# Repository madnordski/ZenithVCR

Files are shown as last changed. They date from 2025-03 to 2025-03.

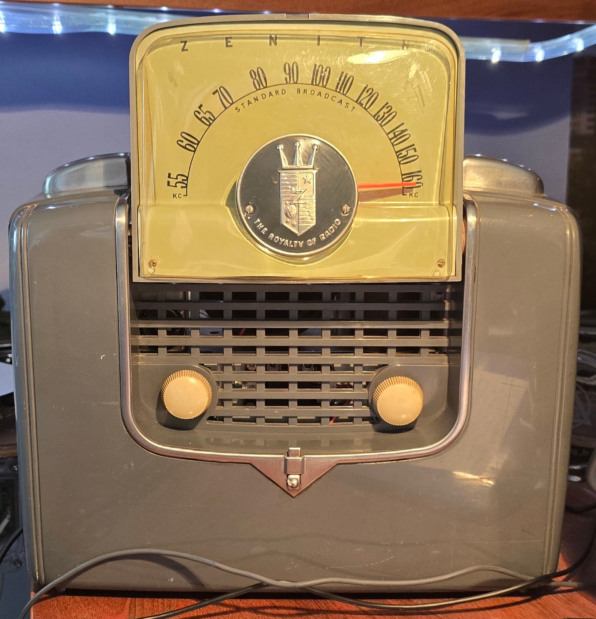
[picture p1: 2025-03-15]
Parts/Zenith4G90t2.jpg

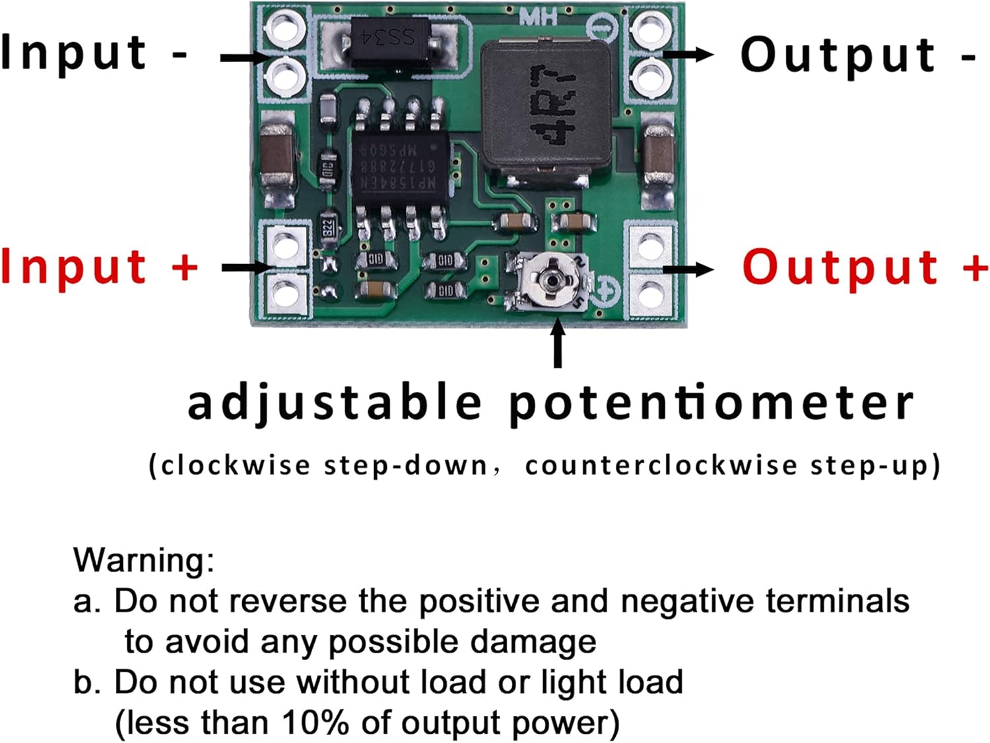
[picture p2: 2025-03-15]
Parts/adjustable_buck_converter1.jpg

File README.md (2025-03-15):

# ZenithVCR
This repository is for the **Zenith Voice Controlled Radio**.
- by J.King, March 2025
- Special thanks to OpenAI’s ChatGPT for assistance with debugging, Flask optimization, and streaming improvements.
## 🎵 Overview
This project brings a **1940s Zenith Radio** back to life with modern streaming capabilities! It features:
- **ESP32-S3 N8R2 DevKitC** as the core controller (w/at least 2MB PSRAM).
- **Python Flask Server** for serving music, managing playlists and serving podcasts.
- **Voice control** via the **DFRobot SEN0539-EN** module.
- **Stepper-motor-controlled tuning dial** for station selection.
- **Wi-Fi connectivity** with adaptive access point switching.

## 🛠️ Features
✅ **Stream Internet Radio, Podcasts, and Local MP3/OGG Files**  
✅ **Control Playback via Voice Commands or Encoder Knob w/Button**  
✅ **mDNS for Easy Web Interface Access**  
✅ **Multi-Threaded Flask Server for Smooth UI & Streaming**  
✅ **Auto-Switching Between Wi-Fi Access Points**  
✅ **Creates Access Point for Easy WiFi Setup**  
✅ **Web Interface for entering Internet Radio Station URLs**

## 🔧 Hardware Used
- **ESP32-S3 DevKitC-1 (YD-ESP32-S3 N8R2)**
- **DFRobot SEN0539-EN Speech Recognition Module**
- **Stepper Motor (PM08-2) & Controller (TMC2209) for Dial Pointer**
- **Permanent Magnet Speaker (Replaced Original Field Coil)**
- **9V 3A Power Supply + Buck/Boost Converters**
- **Vintage 1940s Zenith 4G903 Radio Chassis**

## 🖥️ How It Works
### **1️⃣ Python Flask Server (Raspberry Pi / Linux)**
- Hosts music via **FFmpeg for real-time transcoding**.
- Serves a **web-based album browser at http://zenithvcr:8001/** for easy selection.
- Runs two Flask servers:
  - **Port 8000:** Streaming server (used by ESP32 to play local content).
  - **Port 8001:** Web UI for album selection.
- **mDNS** so any computer on your network can find the Flask servers**
  - **http://zenithvcr:8001/browse**

### **2️⃣ ESP32-S3 (Zenith Voice Controlled Radio)**
- Fetches music from the server.
- Uses **I²C speech recognition** for voice control.
- Switches between **Internet radio, local MP3s, and podcasts**.
- The station playing is indicated by an **interactive tuning dial**.
- **Serves a webpage at zenith.local** for changing Internet Radio URLs.
  - this page also includes a complete list of the voice commands.
- Press and hold the volume knob when turning on to setup WiFi for your network.
  - Connect to access point, **Zenith Setup** and IP **192.168.1.4**.

## 🚀 Installation & Setup
### **1** Optionally, Set Up the Flask Music Server
The Zenith Voice Controlled Radio does not depend on the Flask Server.
It's used only to serve your local content to the Zenith.
#### **Install Dependencies**
```sh
pip install flask gevent ffmpeg-python
python3 stream_machine.py
```
### **2** Flash the ESP32 with the Radio Firmware
Use Arduino IDE or PlatformIO to upload the code.
🎙️ Voice Commands
(these are configured by you.  Follow the DFRobot SEN0539 instructions).
The code burned into the ESP32 is ready to respond to commands
like the following.  Use http://zenith.local to associate your voice
commands to all the tasks defined in the code.
### Command	Action (complete list at zenith.local)
#### "Hello robot, pause radio"	  stops playback
#### "Hello robot, resume radio"	resumes where it left off
#### "Hello robot, volume up"     turns up the volume
#### "Hello robot, volume down"   turns down the volume
#### "Hello robot, station up"    moves the dial up one station
#### "Hello robot, station down"  moves the dial down one station

### **3** Put the Zenith Voice Controlled Radio on your Network
When the Zenith runs for the first time, it creates an access point called "Zenith Setup".
You can always force the Zenith into access point mode by holding in the volume knob when
powering on.
#### Step a. Connect your phone or computer WiFi to Zenith Setup.
#### Step b. Go to http://192.168.1.4 to enter the WiFi Credentials
#### Step c. Update and restart the Zenith (follow instructions)
#### Step d. Now you can define your Internet radio stations using http://zenith.local.
#### Step e. Enjoy!
#### Step f. If you are running the Flask server, enter the streaming url (use IP) at http://zenith.local.

🎛️ Web Interface for locally served content (Flask Server)
### Access the album browser at http://zenithvcr.local:8001
### Stream control handled at http://zenithvcr.local:8000/stream
⚡ Troubleshooting
### Problem: Web interface is slow while streaming
✅ Solution: Flask now runs two separate servers (8000 & 8001) to keep the UI responsive.

### Problem: ESP32 disconnects and Flask hangs
✅ Solution: Improved error handling ensures FFmpeg stops properly.

### Problem: Album names with special characters break requests
✅ Solution: URLs are properly encoded & decoded in JavaScript and Flask.

📜 License
### GPL-3.0 - Open Source! Feel free to modify and improve provided you pass on your work to others.

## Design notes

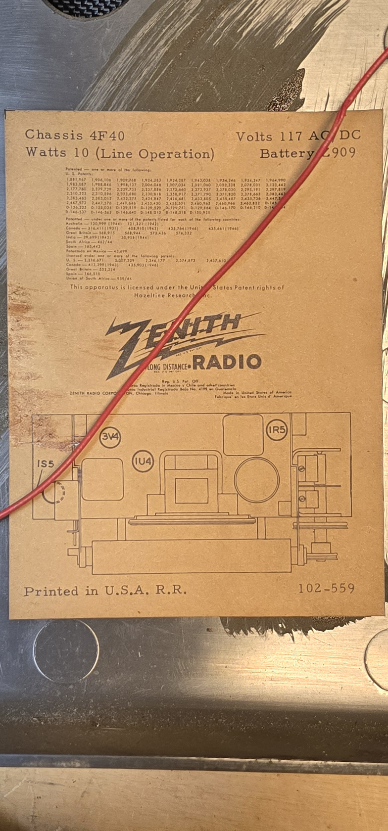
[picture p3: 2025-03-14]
photos/20250121_075358_resized.jpg

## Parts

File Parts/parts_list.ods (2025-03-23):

Zenith Voice Controlled Radio Parts List
Part | Link (non-sponsored)
ESP32-S3 DevKitC-1 N8R2 | https://www.amazon.com/dp/B0DFTKFWT2?ref_=ppx_hzsearch_conn_dt_b_fed_asin_title_1
DFRobot SEN0539 | https://www.dfrobot.com/product-2665.html
Stepper Motor | https://www.amazon.com/dp/B08346RFVZ?ref_=ppx_hzsearch_conn_dt_b_fed_asin_title_3
TMC2209 | https://www.amazon.com/HiLetgo-Printer-TMC2209-Stepper-Replace/dp/B0832SK397
MAX98357 | https://www.amazon.com/dp/B0912CWB7Z?ref_=ppx_hzsearch_conn_dt_b_fed_asin_title_1&th=1
Rotary Encoders (2) | https://www.amazon.com/dp/B09KNC1J6H?ref_=ppx_hzsearch_conn_dt_b_fed_asin_title_1
Reed switch | https://www.amazon.com/dp/B07WQVLRQC?ref_=ppx_hzsearch_conn_dt_b_fed_asin_title_1
Speaker (for radio) | https://www.amazon.com/dp/B001RNNX8U?ref_=ppx_hzsearch_conn_dt_b_fed_asin_title_1&th=1
Speaker (for DFRobot) | https://www.amazon.com/dp/B0C49TKSQQ?ref_=ppx_hzsearch_conn_dt_b_fed_asin_title_3&th=1
Adjustable Buck Converter (before wiring, adjust to 5.1 volts) | https://www.amazon.com/dp/B07RVG34WR?ref_=ppx_hzsearch_conn_dt_b_fed_asin_title_1&th=1
USB Buck Converter | https://www.amazon.com/dp/B01HXU1C6U?ref_=ppx_hzsearch_conn_dt_b_fed_asin_title_1
9V Power Supply | https://www.amazon.com/dp/B08L99PTDH?ref_=ppx_hzsearch_conn_dt_b_fed_asin_title_1&th=1
Red LED
Green LED
220 ohm resisters (2)
1K ohm resistor
100K ohm resistor

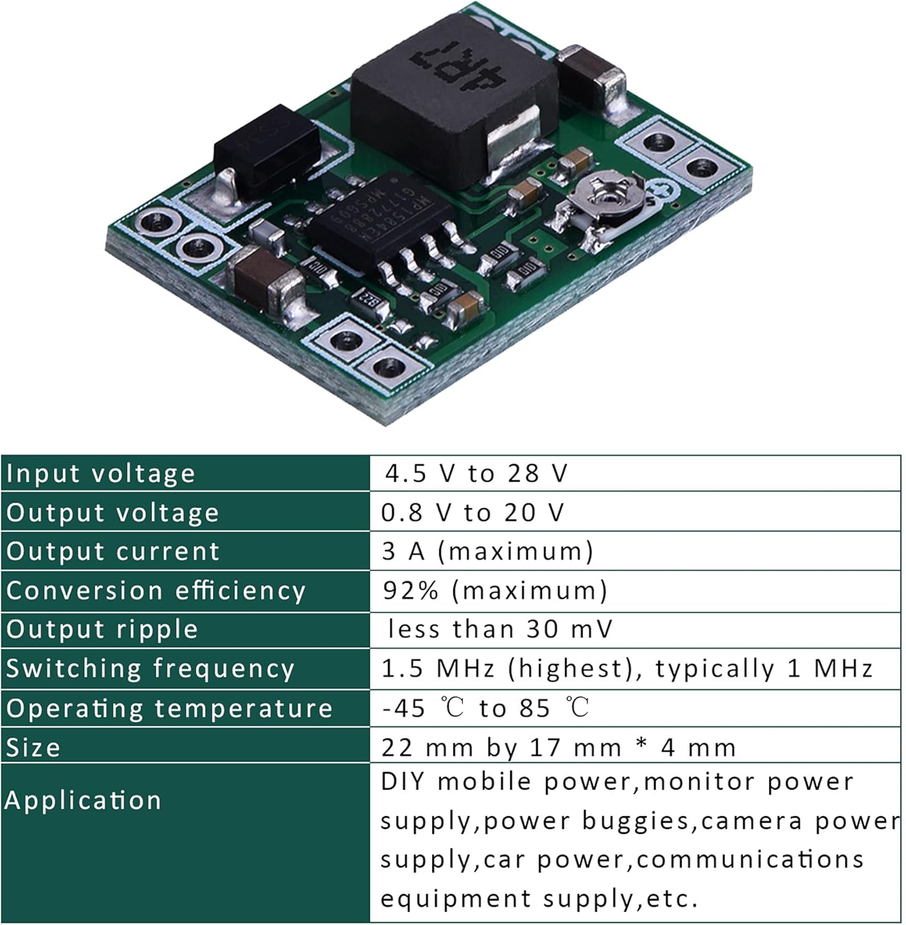
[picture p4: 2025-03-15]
Parts/adjustable_buck_converter2.jpg

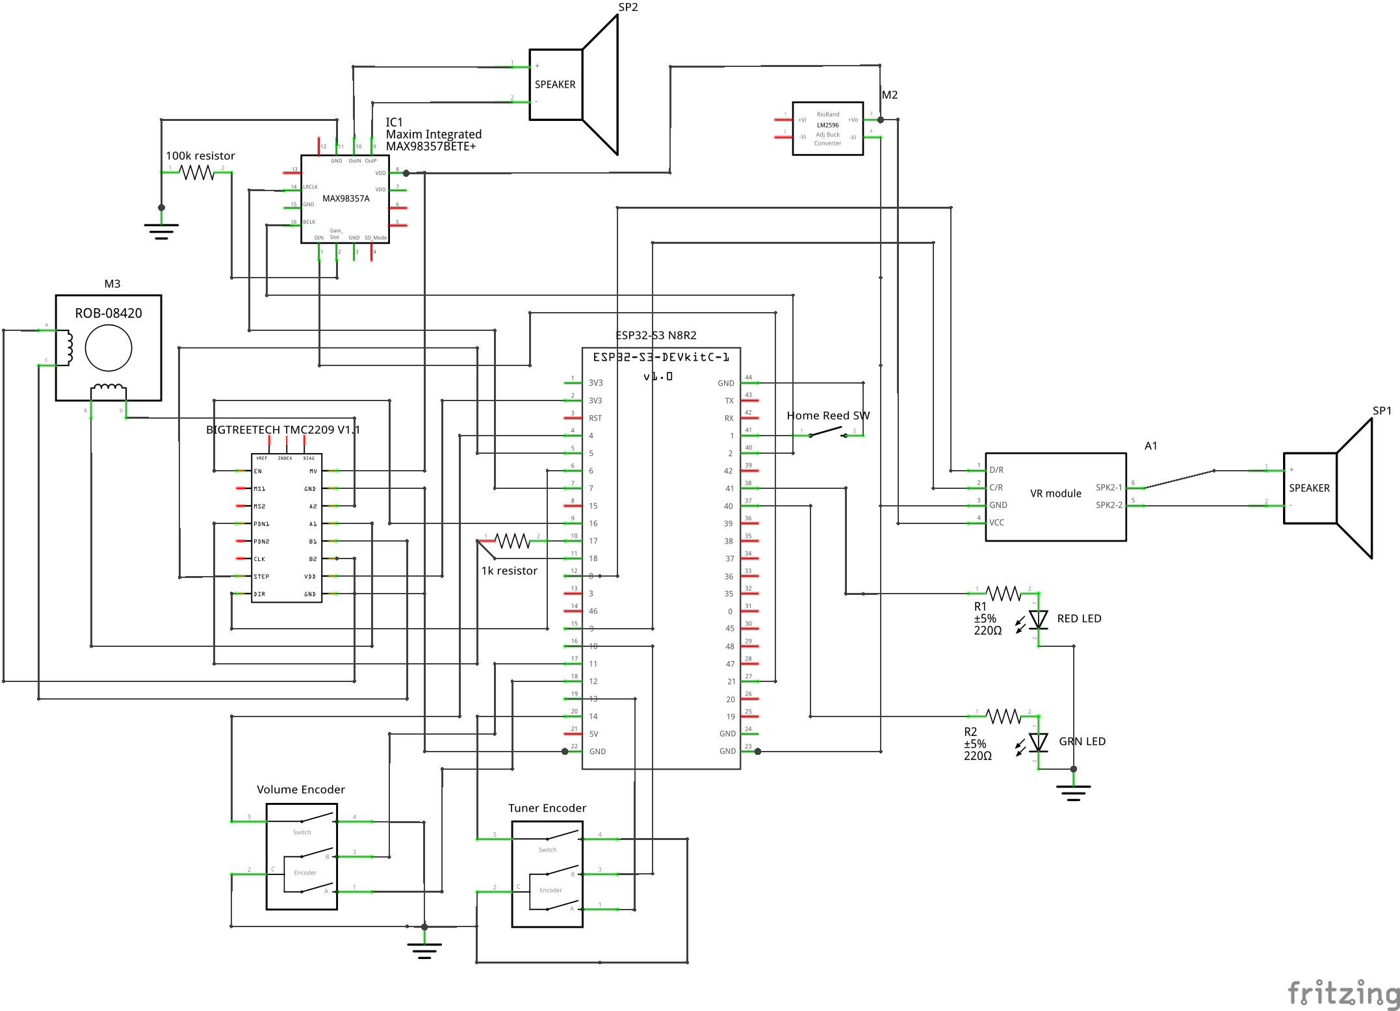
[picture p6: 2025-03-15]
Parts/zenith_schem.png

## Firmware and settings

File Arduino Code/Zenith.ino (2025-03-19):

/** Zenith

  The Zenith Voice Controlled Internet Radio. The idea is we will
  replace the innards of a vintage radio with an ESP32-S3 that plays
  Internet radio and is controlled by voice commands.

  Voice control is handled by the DFRobot SEN0539 Language Recognition
  Sensor. This sensor is able to learn one wake-word and 17 voice
  commands. It conects to our ESP32-S3 over I2C.

  IMPORTANT: The Zenith serves a webpage for configuring the WiFi and
  Internet Radio URLs.  When it is unable to connect to WiFi or WHEN
  THE VOLUME KNOB IS PRESSED IN AT STARTUP, Zenith creates an access
  point called "Zenith Setup" and serves the webpage at 192.168.1.4.
  You can always access this webpage when Zenith is on your home WiFi
  by going to http://zenith.local.
  
  The ESP32 has a stepper motor under its control that moves the dial
  pointer. The stepper driver is the TMC2209 and is controlled to the
  ESP32 by a few GPIO pins and configured using a hardward serial
  UART.  There is a small magnet on the pointer that is sensed by a
  reed switch mounted under the dial face. This is used to home the
  pointer at startup.

  Being an Internet radio, the ESP32-S3 sends audio over I2S (not a
  typo), to a MAX98357 audio amplifier.

  Finally, the operations of the volume and tuner knobs are handled by
  two rotary encoders. The volume knob controls volume and pressing it
  in toggles the mute state.  The Tuner know controls which Internet
  radio station is playing. Pressing the turn knob in only matters
  with the radio is tuned to a local stream (special channel). When
  this is the case, pressing the tuner in will play the next track in
  the stream.
  
  @author J. King
  @date 5 February 2025
  @copy All rights reserved.
  @brief discription
  
  $Revision: 1.57 $
  $Date: 2025/03/19 21:15:12 $

*/

// Include required libraries
#include <Arduino.h>
#include <esp_system.h>
#include <Preferences.h>

#include <WiFi.h>
#include <ESPmDNS.h>
#include "Audio.h"
#include <HardwareSerial.h>
#include <TMCStepper.h>
#include "DFRobot_DF2301Q.h"
#include "GetRequestParser.h"
#include "index.h"
#include "index2.h"
#include "index3.h"

// debug
//#define DEBUG

#ifdef DEBUG
#define sp1(x)   Serial.println(x)
#define sp2(x,y) Serial.print(x);Serial.println(y)
#define sp2s(x,y) Serial.print(x);Serial.print(" ");Serial.println(y)
#else
#define sp1(x)
#define sp2(x,y)
#define sp2s(x,y)
#endif

// simplify serial print when debugging isn't desired
#define sp2sx(x,y) Serial.print(x);Serial.print(" ");Serial.println(y)
#define sp2x(x,y) Serial.print(x);Serial.println(y)
#define sp1x(x)   Serial.println(x)

// CONNECTION FOR YD ESP32-S3 DEVKITC-1 N8R2 (2 MB PSRAM, 8 MB FLASH)
// GPIO

const gpio_num_t mutePin = GPIO_NUM_4;      // the volume encoder push button
const gpio_num_t nextTrackPin = GPIO_NUM_14; // the favorite station push button

// Define I2S connections for audio output
#define I2S_DOUT  GPIO_NUM_21
#define I2S_BCLK  GPIO_NUM_2   // sck
#define I2S_LRC   GPIO_NUM_7  // ws

// STATION LIST
#define STATION_LIMIT       13  // 13 STATION LIMIT, one for each dial number
#define STATION_CHAR_LIMIT 256  // character length limit for station entries

// the station list set of keys
char *staIds[] = {"sta55", "sta60", "sta65", "sta70", "sta80", "sta90",
		  "sta100", "sta110", "sta120", "sta130", "sta140",
		  "sta150", "sta160"};

// the task ids, set of keys
const int nTaskIds = 17;
char *tskIds[] = {"tsk10", "tsk11", "tsk12", "tsk13", "tsk14", "tsk15",
		  "tsk16", "tsk17", "tsk18", "tsk19", "tsk20",
		  "tsk21", "tsk22", "tsk23", "tsk24", "tsk25", "tsk26"};

// normal loop or settings loop
bool gAPMode = false;

// we will populate this list from preferences and have web page for
// configuring new or additional stations up STATION_LIMIT (limited to
// 13), one for each dial number.

char *gStationList[STATION_LIMIT] = {0};
int gNumberOfStations = 0;
const int localStreamPos = 11;
const int localPodcastPos = 12;
bool gSkipRequest = false;

// COMMAND LIST -- populated from violet unless fails then prefs
// This list maps voice commands to tasks.

#define COMMAND_LIMIT      256
int8_t gCommands[COMMAND_LIMIT];  // sparsely populated lookup table
int gNumCommands = 0;

// Save the last station used, the volume level, wifi settings and the
// list of stations to preferences.

Preferences prefs;

// I2C for communicating with the DFRobot SENS0539-EN voice
// recognition module

DFRobot_DF2301Q_I2C zenith;

// Create audio object
Audio audio;

// Wifi Credentials, taken from prefs
char ssids[2][32];  
char password[2][80];
int gCurrentSSID = 0;
const int rssiMinimum = -65; // switch access points when signal gets
			     // marginal

// WiFi Access Point for setting passwords and station urls
const char *apSSID = "Zenith Setup";

// we also run an http server for configuring the Zenith VC Radio
NetworkServer server(80);

// LEDs
const gpio_num_t grnLed = GPIO_NUM_40;
const gpio_num_t redLed = GPIO_NUM_41;

// reed switch for homing
const int homePin = GPIO_NUM_1;

// stepper motor definition
#define EN_PIN    GPIO_NUM_16   // Enable pin (wired to ground)
#define DIR_PIN   GPIO_NUM_6   // Direction pin
#define STEP_PIN  GPIO_NUM_5   // Step pin
#define UART_RX   GPIO_NUM_18   // UART RX (TMC2209 TX)
#define UART_TX   GPIO_NUM_17   // UART TX (TMC2209 RX)

#define R_SENSE 0.11f    // Sense resistor value
#define DRIVER_ADDRESS 0 // Default address for TMC2209

#define DIRECTION_CW  LOW
#define DIRECTION_CCW   HIGH
#define SPEED_FAST   10  // might be too fast for most tasks
#define SPEED_MEDIUM 5
#define SPEED_SLOW   0

#define STEPPER_CURRENT 80 // around 56 mA is as low as it will go
#define STEPPER_SPEED   SPEED_SLOW
#define MICRO_STEPS     16

// This are emperically determined stepper positions for each dial
// number.
// Zero is when the needle is against the left stop.
const int numPos = 14;
const int dialPosition[] = {0, 9, 25, 39, 50, 67, 80, 92, 105,
			  //  55  60  65  70  80  90 100  110
			    116, 126, 137, 146, 157};
                         // 120  130  140  150  160

int gCurrentIndex = 0;

// this configures the stepper motor driver with a serial connect
TMC2209Stepper driver(&Serial1, R_SENSE, DRIVER_ADDRESS);

// Tuner and Volume encoder definitions
#define TUNER_APIN GPIO_NUM_13
#define TUNER_BPIN GPIO_NUM_10
#define VOLUME_APIN GPIO_NUM_12
#define VOLUME_BPIN GPIO_NUM_11
#define MAX_VOLUME 100

// timing constants
const unsigned long encDebounceMS = 10;
const unsigned long encWindow = 500; // consistent results or forget

// encoder knob position
volatile int gTunEncoderPos = 0;
volatile int gVolEncoderPos = 22;
volatile unsigned long gPlayStart = 0;
volatile unsigned long gPlayTime = 0;

///////////////  INTERRUPTS ///////////////////////////////////////

/** tunerEncoderISR
    This interrupt updates the value stored in gTunEncoderPos.
    This is triggered on an A pulse, the state of B tells us the
    direction. Because encoders are mechanical switches, we need to
    debounce them.
*/

// Tuner (T) ISR function for reading A pulses
unsigned long encTLastPulse = 0;
int lastTResult = 0; // require pause before changing direction

static void IRAM_ATTR tunerEncoderISR(void *arg) {
  int8_t bStateSum = 0;
  int8_t result;
  int rtn = gTunEncoderPos;
  
  for (int i=0; i<4; i++) {
    bStateSum += digitalRead(TUNER_BPIN) == HIGH ? 1 : 0; // try to debounce B
    delayMicroseconds(100);
  }

  // only concensus readings are accepted
  if ( bStateSum == 0 || bStateSum == 4 ) {
    result = bStateSum < 2 ? 1 : -1;

    // debounce and delay turning around to get smooth forward or
    // reverse changes
    if ( millis() - encTLastPulse > encDebounceMS ) { // debounce A
      if ( result == lastTResult || millis() - encTLastPulse > encWindow ) {
	rtn = gTunEncoderPos + result;
	lastTResult = result;
	encTLastPulse = millis();
      }
    }
  }
  // clip to our station list
  if ( rtn >= gNumberOfStations )
    gTunEncoderPos = gNumberOfStations - 1;
  else if ( rtn < 0 )
    gTunEncoderPos = 0;
  else
    gTunEncoderPos = rtn;
}

/** volumeEncoderISR
    This interrupt updates the value stored in gVolEncoderPos.
    This is triggered on an A pulse, the state of B tells us the
    direction. Because encoders are mechanical switches, we need to
    debounce them.
 */

// Volume (V) ISR function for reading A pulses
unsigned long encVLastPulse = 0;
int lastVResult = 0; // require pause before changing direction

static void IRAM_ATTR volumeEncoderISR(void *arg) {
  int8_t bStateSum = 0;
  int8_t result;
  int rtn = gVolEncoderPos;
  
  for (int i=0; i<4; i++) {
    bStateSum += digitalRead(VOLUME_BPIN) == HIGH ? 1 : 0; // try to debounce B
    delayMicroseconds(100);
  }

  // accept consensus values only
  if ( bStateSum == 0 || bStateSum == 4 ) {
    result = bStateSum < 2 ? 1 : -1;

    // smooth transiition
    if ( millis() - encVLastPulse > encDebounceMS ) { // debounce A
      if ( result == lastVResult || millis() - encVLastPulse > encWindow ) {
	rtn = gVolEncoderPos + result;
	lastVResult = result;
	encVLastPulse = millis();
      }
    }
  }
  // clip volume
  if ( rtn >= MAX_VOLUME )
    gVolEncoderPos = MAX_VOLUME;
  else if ( rtn < 0 )
    gVolEncoderPos = 0;
  else
    gVolEncoderPos = rtn;
}

/** muteEncoderISR

    This ISR sets the state of gPlay.
    Interrupt routine to handle the button press of the volume
    encoder. It toggles the pause/resume state of Internet Radio.
*/

volatile bool gPlay = true;

unsigned long btnDebounceMS = 500;
unsigned long muteLastPress = 0;
unsigned long muteBtnDebounce = btnDebounceMS * 2;

static void IRAM_ATTR muteEncoderISR(void *arg) {
  if ( millis() - muteLastPress > muteBtnDebounce ) { // debounce
    if ( gPlay )
      gPlay = false;
    else
      gPlay = true;
    muteLastPress = millis();
  }
}

/** nextTrackEncoderISR

    This ISR sets the state of gNextTrack which advances the playback
    of local music one track.
    Interrupt routine to handle the button press of the tuner
    encoder. This button is only active when the station is set to
    STREAM LOCAL.
*/

volatile bool gNextTrack = false;
unsigned long nextTrackPress = 0;

static void IRAM_ATTR nextTrackEncoderISR(void *arg) {
  if ( millis() - nextTrackPress > btnDebounceMS ) { // debounce
    gNextTrack = true;
    nextTrackPress = millis();
  }
}

/** playStationTask

    This task just keeps the radio playing.  The station is selected
    elsewhere.  It is paused by setting gPlay to false.
*/

TaskHandle_t PlayStationHandle;
int gPlayParam = 0;

void playStationTask(void *pvParams) {
  bool state = gPlay;

  while ( true ) {
    if ( gPlay ) {
      audio.loop();
    }
      
    vTaskDelay(1/portTICK_PERIOD_MS);
  }
}

/** zenithVCTask

    This task handles the voice commands.  When you say, "Hello,
    Robot" and the DFRobot SEN0539 recognizes this the wake-word, the
    radio will be paused.  It is then ready to recieve a command.
    BTW: by pressing the volume knob to pause the radio before saying
    "Hello, robot", is adviced.

    There are primary control commands and commands for specific
    Internet Radio Stations.  You can reprogram the DFRobot without
    writing code but the code here would need to change to add and
    delete tasks.  If you reprogram the DFRobot Voice Commands, these
    can be mapped to the tasks coded using a text file served by a
    local webserver.  Changing the webserver IP, however, requires
    modification of this program.
    
    FYI: the purpose of pause/resume radio is to allow programming of
    the DFRobot or for verifying the voice command ids.

*/
    
TaskHandle_t ZenithVCHandle;
int gTaskVar = 0;
bool gRadioOff = false; // use this to train the sen0539 language
			// recognition sensor
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
void loop() {
  if ( !gAPMode ) mainLoop();
  setupLoop();  
}

GetRequestParser reqParser;

void setupLoop() {
  WiFiClient client = server.accept();

  // stannn=url is 7 characters, 4*32 for password settings
  // nb: special characters can extend data beyond the prediction
  // (e.g. & becomes %26) but user input is restricted by characters typed
  //const size_t maxDataSize = 4*32 + STATION_LIMIT*STATION_CHAR_LIMIT;
  const size_t maxLineSize = STATION_LIMIT*7 + STATION_LIMIT*STATION_CHAR_LIMIT;
  const size_t maxValueSize = STATION_CHAR_LIMIT;
  
  if ( client ) {
    char line[maxLineSize];
    int idx = 0;
    bool espRestart = false;
    bool havePost = false;
    bool cmdTskChange = false;
    
    sp1("client connected");
    
    while ( client.connected() ) {
      if ( client.available() ) {
	char c = client.read();
	Serial.write(c);
	
	if ( c == '\n' ) {
	  if ( strstr(line, "POST ") ) {
	    havePost = true;
	  }
	  if ( strstr(line, "GET") ) {
	    char name[maxValueSize], value[maxValueSize];
	    int err;
	    
	    sp2("LINE: ", line);
	    sp2("Line size: ", strlen(line));
	    
	    if ( (err = reqParser.parse(line, false)) == REQPARSE_OKAY ) {
	      sp1("PARSED---------");
	      while ( reqParser.nextRequest(name, value, maxValueSize) ) {
		sp2sx(name, value);
		if ( strcmp(name, "Restart") == 0 ) espRestart = true;
	      }
	      if ( espRestart ) {
		// back to normal operation
		client.clear();
		client.stop();
		ESP.restart();
	      }
	    }
	  }
	  
	  if ( idx == 0 ) {
	    if ( havePost ) {
	      // POST content here
	      sp1("********* POST EVENTS HERE ********");
	      char *p = line;
	      *p = '\0';
	      while ( client.available() ) {
		char c = client.read();
		Serial.write(c);
		*p = c;
		p++;
		*p = '\0';
	      }
	      sp2("L:", line);
	      char name[maxValueSize], value[maxValueSize];
	      int err;
	      cmdTskChange = false;
	      
	      sp2("LINE: ", line);
	      sp2("Line size: ", strlen(line));
	      
	      if ( (err = reqParser.parse(line, true)) == REQPARSE_OKAY ) {
		while ( reqParser.nextRequest(name, value, maxValueSize) ) {
		  sp2sx(name, value);
		  if ( strstr(name, "tsk") == NULL ) {
		    prefs.putString(name, value); // update the string settings
		  }
		  if ( strcmp(name, "ssid1") == 0 ) strcpy(ssids[0], value);
		  if ( strcmp(name, "ssid2") == 0 ) strcpy(ssids[1], value);
		  if ( strcmp(name, "pw1") == 0 ) strcpy(password[0], value);
		  if ( strcmp(name, "pw2") == 0 ) strcpy(password[1], value);
		  for (int i=0; i<STATION_LIMIT; i++) {
		    if ( strcmp(name, staIds[i]) == 0 ) {
		      strcpy(gStationList[i], value);
		    }
		  }
		  // update integer settings
		  for (int i=0; i<nTaskIds; i++) {
		    if ( strcmp(name, tskIds[i]) == 0 ) {
		      int cId = atoi(value);
		      int tId = atoi(name+3);
		      sp2sx(cId, tId);
		      if ( cId >= 0 && cId < COMMAND_LIMIT ) {
			// update prefs, before we can update the
			// gCommands table, we need to clear it out
			// (see below)
			prefs.putInt(name, cId);
			cmdTskChange = true;
		      }
		    }
		  }
		}
	      }
	      else {
		if ( err == REQPARSE_NO_QUERY_ERR ) {
		  sp2("No query error ", err);
		}
		else if ( err == REQPARSE_MALLOC_ERR ) {
		  sp2("Memory allocation error ", err);
		}
		else {
		  sp2("Unspecified error ", err);
		}
	      }
	      Serial.println("********* END POST EVENTS *************");
	    }

	    // IF CMD/TSK CHANGE: NEED TO CLOSE AND REOPEN PREFERENCES
	    //  this clears the cache and prevents busy errors
	    // use prefs, it gives us a lookup by task id
	    // start a reply
	    if ( cmdTskChange ) {
	      prefs.end();
	      prefs.begin("Zenith");
	      // reestablish the sparse command to task array
	      for (int i=0; i<COMMAND_LIMIT; i++) {
		// must clear out changed values
		gCommands[i] = 0;
	      }
	      for (int i=0; i<nTaskIds; i++) {
		// populate with the currently saved settings
		int cId = prefs.getInt(tskIds[i]);
		int tId = atoi(tskIds[i]+3);
		gCommands[cId] = tId;
	      }
	    }

	    // response starts here
	    client.println("HTTP/1.1 200 OK");
	    client.println("Content-type:text/html");
	    client.println();

	    // html text of the page
	    client.print(index_html);
	    
	    // Let's try to calculate the predicted data size to determine
	    // allocated size for the first set to data values
	    sp2("size of index2 = ", sizeof(index2_html));
	    size_t predictedSize = sizeof(index2_html) + 4 * 80;
	    for (int i=0; i<STATION_LIMIT; i++) {
	      predictedSize += (strlen(gStationList[i])+1);
	    }
	    
	    // send back the settings for wifi and urls
	    char *buf1 = (char *)malloc(predictedSize);
	    if ( buf1 == NULL ) {
	      sp1x("Failed to allocate memory!!!");
	      vTaskDelay(100000/portTICK_PERIOD_MS);
	    }

	    snprintf(buf1, predictedSize, index2_html,
		    ssids[0], password[0], ssids[1], password[1], //  4
		    gStationList[0], gStationList[1],
		    gStationList[2], gStationList[3],
		    gStationList[4], gStationList[5],            // 10
		    gStationList[6], gStationList[7],
		    gStationList[8], gStationList[9],
		    gStationList[10], gStationList[11],           // 16
		    gStationList[12]
		    );

	    // did we exceed the length!?! (should be impossible)
	    sp2("allocated buf1: ", predictedSize);
	    sp2("buf1 size: ", strlen(buf1));
	    if ( strlen(buf1) >= predictedSize ) {
	      sp1x("\n************ WEB PAGE MEMORY EXCEEDED **************");
	      sp1x("restarting...");
	      ESP.restart();
	    }
	    sp1("Sending to client...");
	    sp2("Heap ", ESP.getFreeHeap());
	    client.print(buf1);
	    free(buf1);

	    // Let's try to calculate the predicted data size to determine
	    // allocated size for the second set to data values
	    sp2("size of index3 = ", sizeof(index3_html));
	    predictedSize = sizeof(index3_html) + 8 * nTaskIds;
	    
	    // send back the settings for wifi and urls
	    buf1 = (char *)malloc(predictedSize);
	    if ( buf1 == NULL ) {
	      sp1x("Failed to allocate memory!!!");
	      vTaskDelay(100000/portTICK_PERIOD_MS);
	    }

	    snprintf(buf1, predictedSize, index3_html,
		     prefs.getInt("tsk10"), prefs.getInt("tsk11"),
		     prefs.getInt("tsk12"), prefs.getInt("tsk13"),
		     prefs.getInt("tsk14"), prefs.getInt("tsk15"),
		     prefs.getInt("tsk16"), prefs.getInt("tsk17"),
		     prefs.getInt("tsk18"), prefs.getInt("tsk19"),
		     prefs.getInt("tsk20"), prefs.getInt("tsk21"),
		     prefs.getInt("tsk22"), prefs.getInt("tsk23"),
		     prefs.getInt("tsk24"), prefs.getInt("tsk25"),
		     prefs.getInt("tsk26")
		    );

	    // did we exceed the length!?! (should be impossible)
	    sp2x("allocated buf1: ", predictedSize);
	    sp2x("buf1 size: ", strlen(buf1));
	    if ( strlen(buf1) >= predictedSize ) {
	      sp1x("\n************ WEB PAGE MEMORY EXCEEDED **************");
	      sp1x("restarting...");
	      ESP.restart();
	    }
	    sp1x("Sending final part to client...");
	    sp2x("Heap ", ESP.getFreeHeap());
	    client.print(buf1);
	    vTaskDelay(500/portTICK_PERIOD_MS);
	    free(buf1);

	    // end of response
	    client.println();
	    break;
	  }
	  else {
	    idx = 0;
	    line[idx] = '\0';
	  }
	}
	else if ( c != '\r' ) {
	  line[idx] = c;
	  idx++;
	  line[idx] = '\0';
	  if ( idx > maxLineSize ) {
	    sp2("Line size exceeded!!! Size=", idx);
	  }
	}
      }
    } // end while client connected

    // clear the channel and stop the client
    idx = 0;
    client.clear();
    client.stop();
    sp1("Client disconnected.\n");
  } // end if client
} // end setupLoop
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

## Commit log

2025-03-14 Photos from the build
    All the original wiring and small components were removed. Several capacitors had been blown out completely. The tuner dial pointer was attached to a stepper motor and is now controlled by the ESP32 via voice command or by turning tuner encoder knob. A small magnet mounted to the base of the pointer and a reed switch mounted under the pointer were used to home the pointer. The volume pot was also replaced by an encoder. The field coil speaker was replaced with a fixed magnet speaker. The voice control unit (DFRobot SEN0539) has it's own audio output so there are two speakers mounted inside the radio. The radio speaker had to be mounted back from the front of the uni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
2025-03-17 stream mp3 instead of ogg, simplify and save
    Stream format changed to mpeg, simplified streaming and now we save the currently playing artist when we exit.
2025-03-19 fixed bugs related to voice commands
    [Zenith.ino]
2025-03-23 Now it's complete
    [parts_list.ods]
